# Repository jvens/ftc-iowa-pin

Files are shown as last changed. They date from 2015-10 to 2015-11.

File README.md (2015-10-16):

# FTC Iowa Pin

## Description
The FTC Iowa Pin is a small lapel pin in the shape of Iowa containing 24 low power LEDs making the FIRST logo.  The controler is a 8-bit PIC microcontroller made by Microchip.  The power comes from a single CR2032 battery giving the pin XX hours of continous use before the battery needs to be changed.  

## Hardware
The hardware can be split into three main sections: power, LED drivers, and MCU.  There are many ways that the circuit can be populated for various battery life to cost tradeoffs.  These will be better documented after the boards have been fully tested.  

### Power
The main power comes from a single CR2032 Lithium-Ion battery providing 225mA-hr of energy.  The battery supplies a voltage of 2-3 volts nominally which directly powers the MCU circuity (ToDo: add ability to use an LDO if I need a 1.8 V regulated supply).  The battery also drives the step up circuity which is made up of a boost regulator and optional charge pump.  The circuit contains pads for two different boost options and one charge pump options, and jumpers to choose between options.  The output of the step up circuit is 6 volts which is used to power the LED drivers.

### LED Drivers
The LEDs are grouped into 12 sets.  Each set has two LEDs in series.  The sets are grouped into two columns of six rows.  The columns connect Anodes and rows connect Cathodes of the LEDs.  Driving each Anode is a PMOS transistor.  The transistor can be used as a binary switch or an current limiting switch.  When used as a binary switch the pullup resistor turns the switch off when the MCU puts the line to high-Z, and the switch turns on when the MCU drives the line low.  When used as a current limiting switch the MCU outputs an analog voltage using its internal DAC which is amplified by the op-amps to drive the gate.  Each LED is turned on by driving its column high and its row low, and turned off by setting the row to high-Z.

### MCU
The MCU is a PIC16 made by Microchip.  It uses GPIOs to drive the LED rows, and either GPIO or DAC to drive the LED columns.  It also contains a UART Rx line for reprogramming, ICSP for initial programming, and power on reset circuit.  User interaction is done by a capacitive touch pad connecting to the MCU comparator.  The other side of the comparator is driven by the internal DAC to measure the charge time of the touch pad and parallel capacitance.

## Software
ToDo

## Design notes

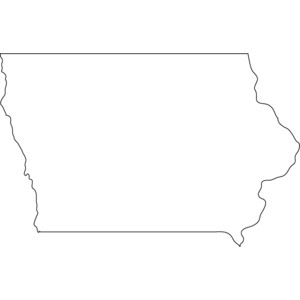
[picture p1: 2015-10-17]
schematic/iowa.jpg

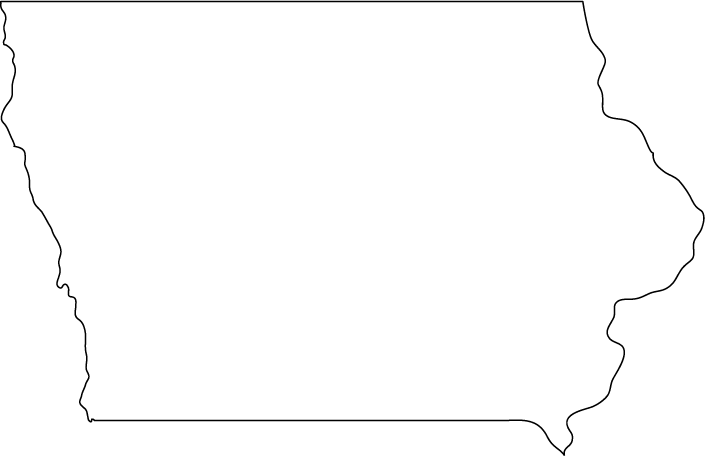
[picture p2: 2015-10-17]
schematic/ia.gif

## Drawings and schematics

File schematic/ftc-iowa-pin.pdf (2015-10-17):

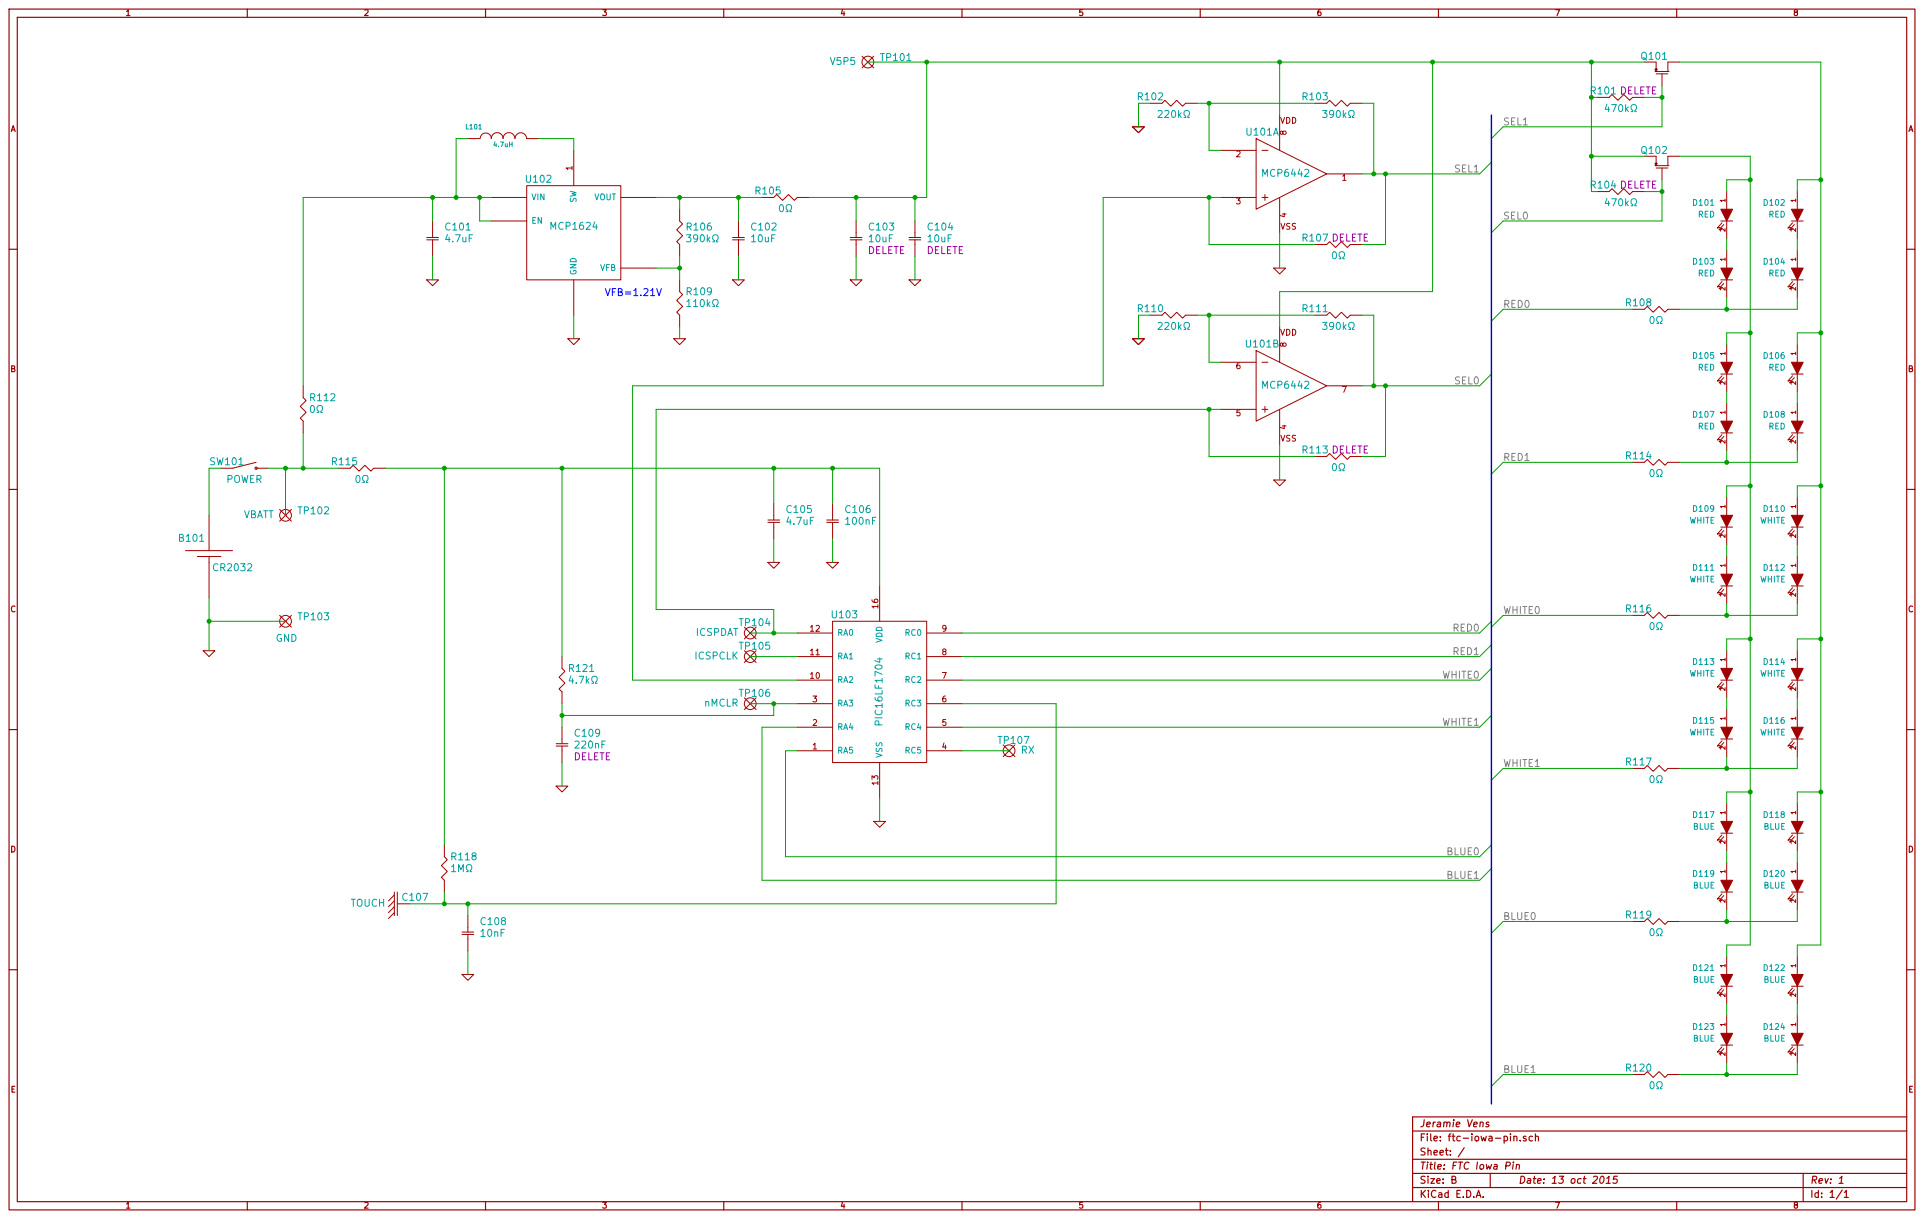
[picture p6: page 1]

Sheet: / Jeramie Vens
File: ftc-iowa-pin.sch

Title: FTC Iowa Pin

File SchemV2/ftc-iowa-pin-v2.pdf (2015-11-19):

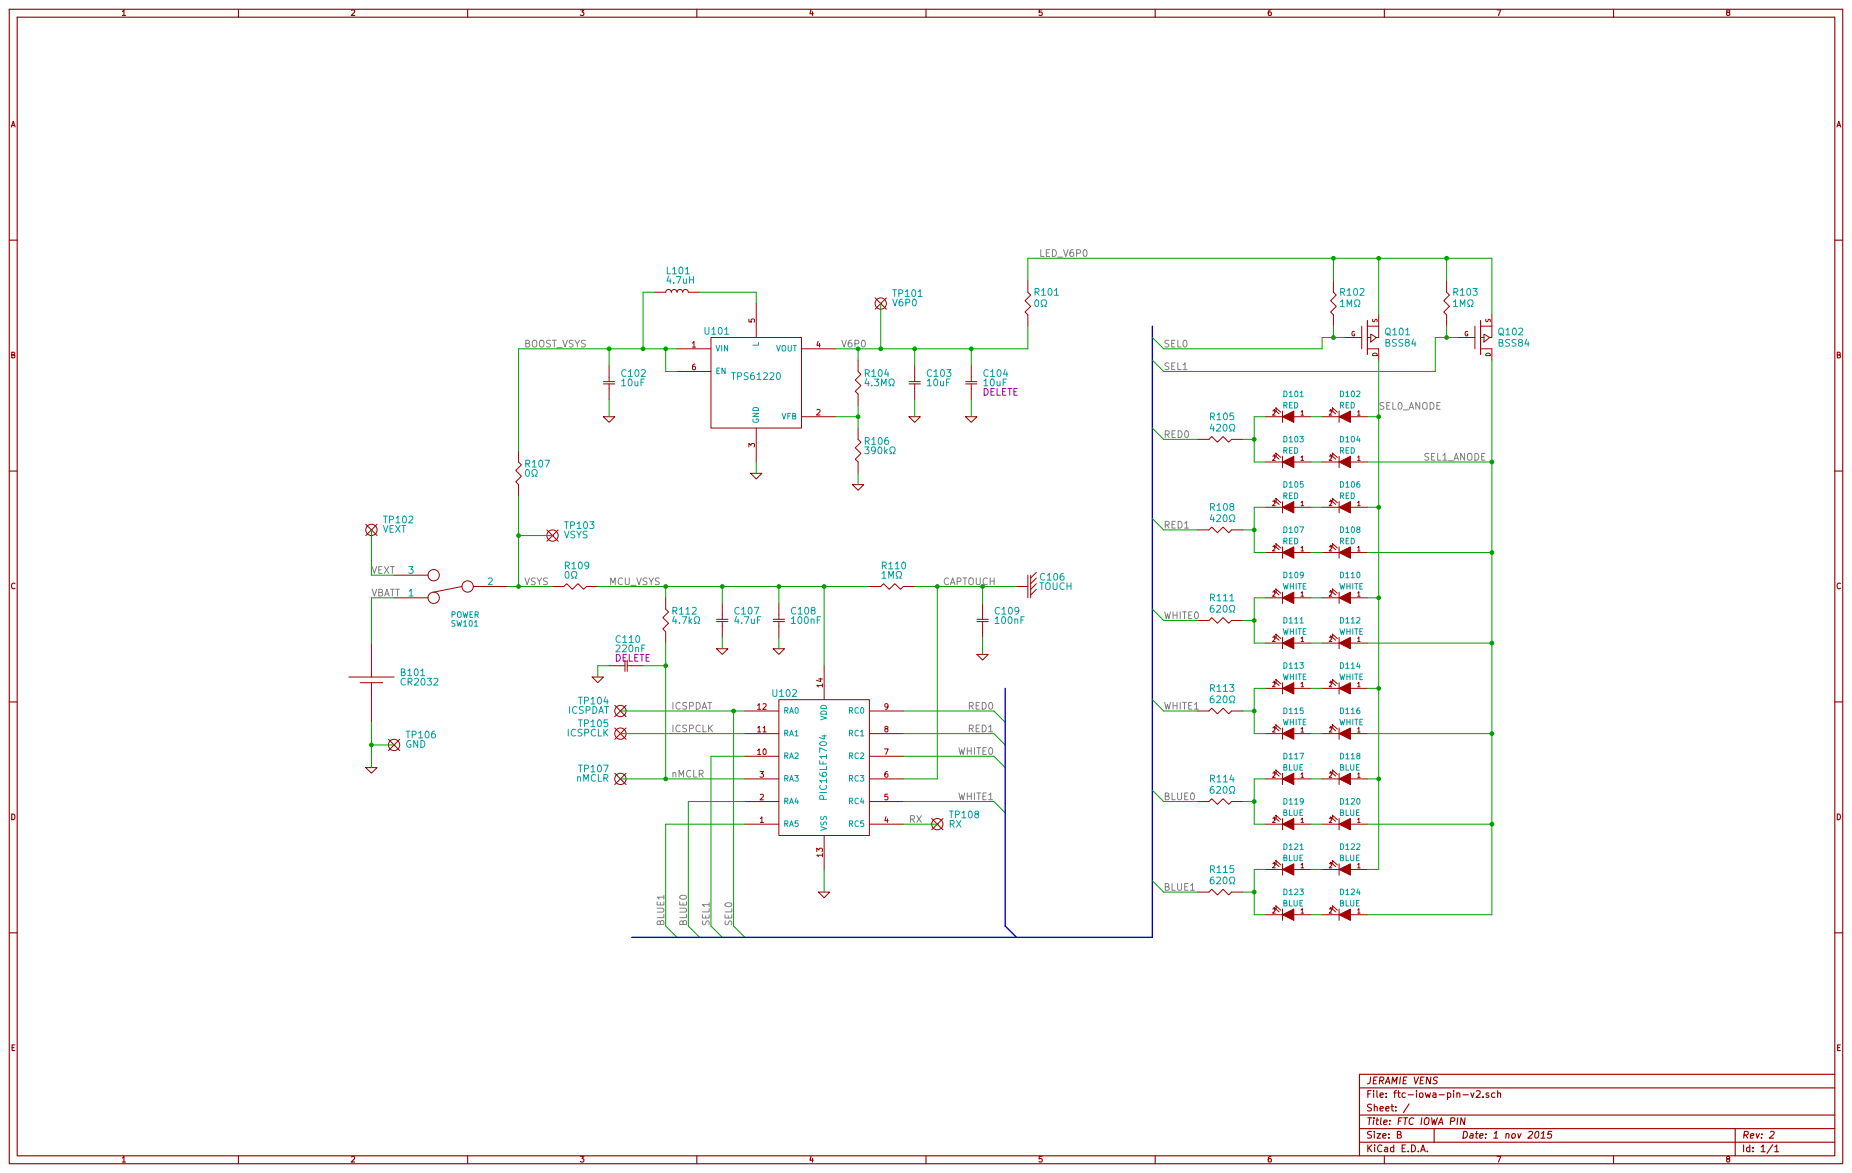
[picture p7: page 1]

JERAMIE VENS
File: ftc-iowa-pin-v2.sch
Sheet: /
Title: FTC IOWA PIN

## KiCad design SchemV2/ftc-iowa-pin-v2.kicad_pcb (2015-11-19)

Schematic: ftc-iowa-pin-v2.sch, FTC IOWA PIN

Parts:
B101: CR2032
C102, C103, C104: 10uF
C106: TOUCH
C107: 4.7uF
C108, C109: 100nF
C110: 220nF
D101, D102, D103, D104, D105, D106, D107, D108: RED
D109, D110, D111, D112, D113, D114, D115, D116: WHITE
D117, D118, D119, D120, D121, D122, D123, D124: BLUE
L101: 4.7uH
Q101, Q102: BSS84
R101, R107, R109: 0Ω
R102, R103, R110: 1MΩ
R104: 4.3MΩ
R105, R108: 420Ω
R106: 390kΩ
R111, R113, R114, R115: 620Ω
R112: 4.7kΩ
SW101: POWER
TP101: V6P0
TP102: VEXT
TP103: VSYS
TP104: ICSPDAT
TP105: ICSPCLK
TP106: GND
TP107: nMCLR
TP108: RX
U101: TPS61220
U102: PIC16LF1704

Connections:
/BLUE0: R114.2, U102.2 (RA4)
/BLUE1: R115.2, U102.1 (RA5)
/BOOST_VSYS: C102.1, L101.1, R107.2, U101.1 (VIN), U101.6 (EN)
/CAPTOUCH: C106.1, C109.1, R110.1, U102.6 (RC3)
/ICSPCLK: TP105.1, U102.11 (RA1)
/ICSPDAT: Q101.G, R102.1, TP104.1, U102.12 (RA0)
/LED_V6P0: Q101.S, Q102.S, R101.2, R102.2, R103.2
/MCU_VSYS: C107.1, C108.1, R109.1, R110.2, R112.2, U102.14 (VDD)
/RED0: R105.2, U102.9 (RC0)
/RED1: R108.2, U102.8 (RC1)
/RX: TP108.1, U102.4 (RC5)
/SEL0_ANODE: D102.1 (A), D106.1 (A), D110.1 (A), D114.1 (A), D118.1 (A), D122.1 (A), Q101.D
/SEL1: Q102.G, R103.1, U102.10 (RA2)
/SEL1_ANODE: D104.1 (A), D108.1 (A), D112.1 (A), D116.1 (A), D120.1 (A), D124.1 (A), Q102.D
/V6P0: C103.1, C104.1, R101.1, R104.2, TP101.1, U101.4 (VOUT)
/VBATT: B101.1, SW101.1
/VEXT: SW101.3, TP102.1
/VSYS: R107.1, R109.2, SW101.2, TP103.1
/WHITE0: R111.2, U102.7 (RC2)
/WHITE1: R113.2, U102.5 (RC4)
/nMCLR: C110.2, R112.1, TP107.1, U102.3 (RA3)
GND: B101.2, C102.2, C103.2, C104.2, C107.2, C108.2, C109.2, C110.1, R106.1, TP106.1, U101.3 (GND), U102.13 (VSS)
unnamed: L101.2, U101.5 (L)
unnamed: D121.2 (K), D123.2 (K), R115.1
unnamed: D121.1 (A), D122.2 (K)
unnamed: D117.2 (K), D119.2 (K), R114.1
unnamed: D119.1 (A), D120.2 (K)
unnamed: D123.1 (A), D124.2 (K)
unnamed: D115.1 (A), D116.2 (K)
unnamed: D113.2 (K), D115.2 (K), R113.1
unnamed: D113.1 (A), D114.2 (K)
unnamed: D109.2 (K), D111.2 (K), R111.1
unnamed: D111.1 (A), D112.2 (K)
unnamed: D105.2 (K), D107.2 (K), R108.1
unnamed: D107.1 (A), D108.2 (K)
unnamed: D105.1 (A), D106.2 (K)
unnamed: D101.2 (K), D103.2 (K), R105.1
unnamed: D103.1 (A), D104.2 (K)
unnamed: D117.1 (A), D118.2 (K)
unnamed: D109.1 (A), D110.2 (K)
unnamed: D101.1 (A), D102.2 (K)
unnamed: R104.1, R106.2, U101.2 (VFB)

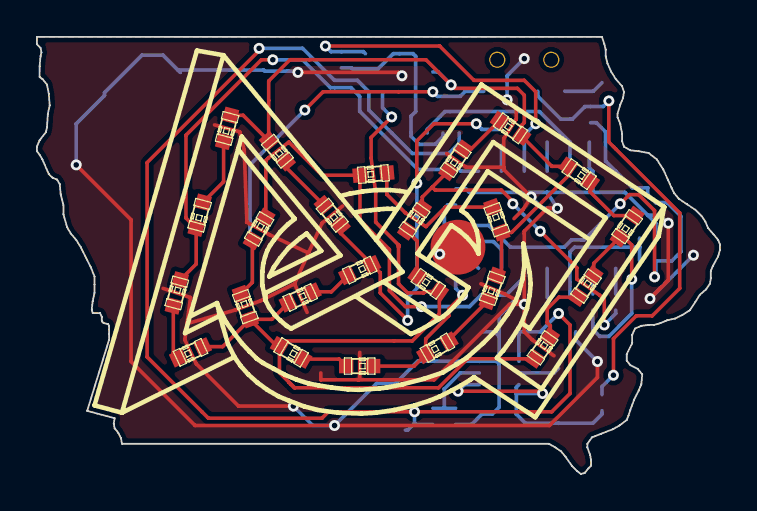
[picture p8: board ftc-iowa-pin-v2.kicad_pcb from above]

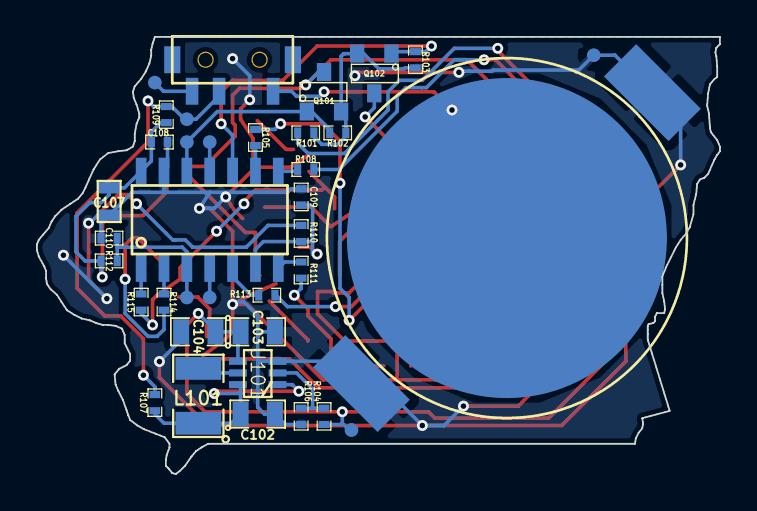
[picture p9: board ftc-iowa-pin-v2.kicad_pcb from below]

Board: 2 copper layers, 37.9 x 24.3 mm, 62 parts (37 on the bottom side), 42 nets.

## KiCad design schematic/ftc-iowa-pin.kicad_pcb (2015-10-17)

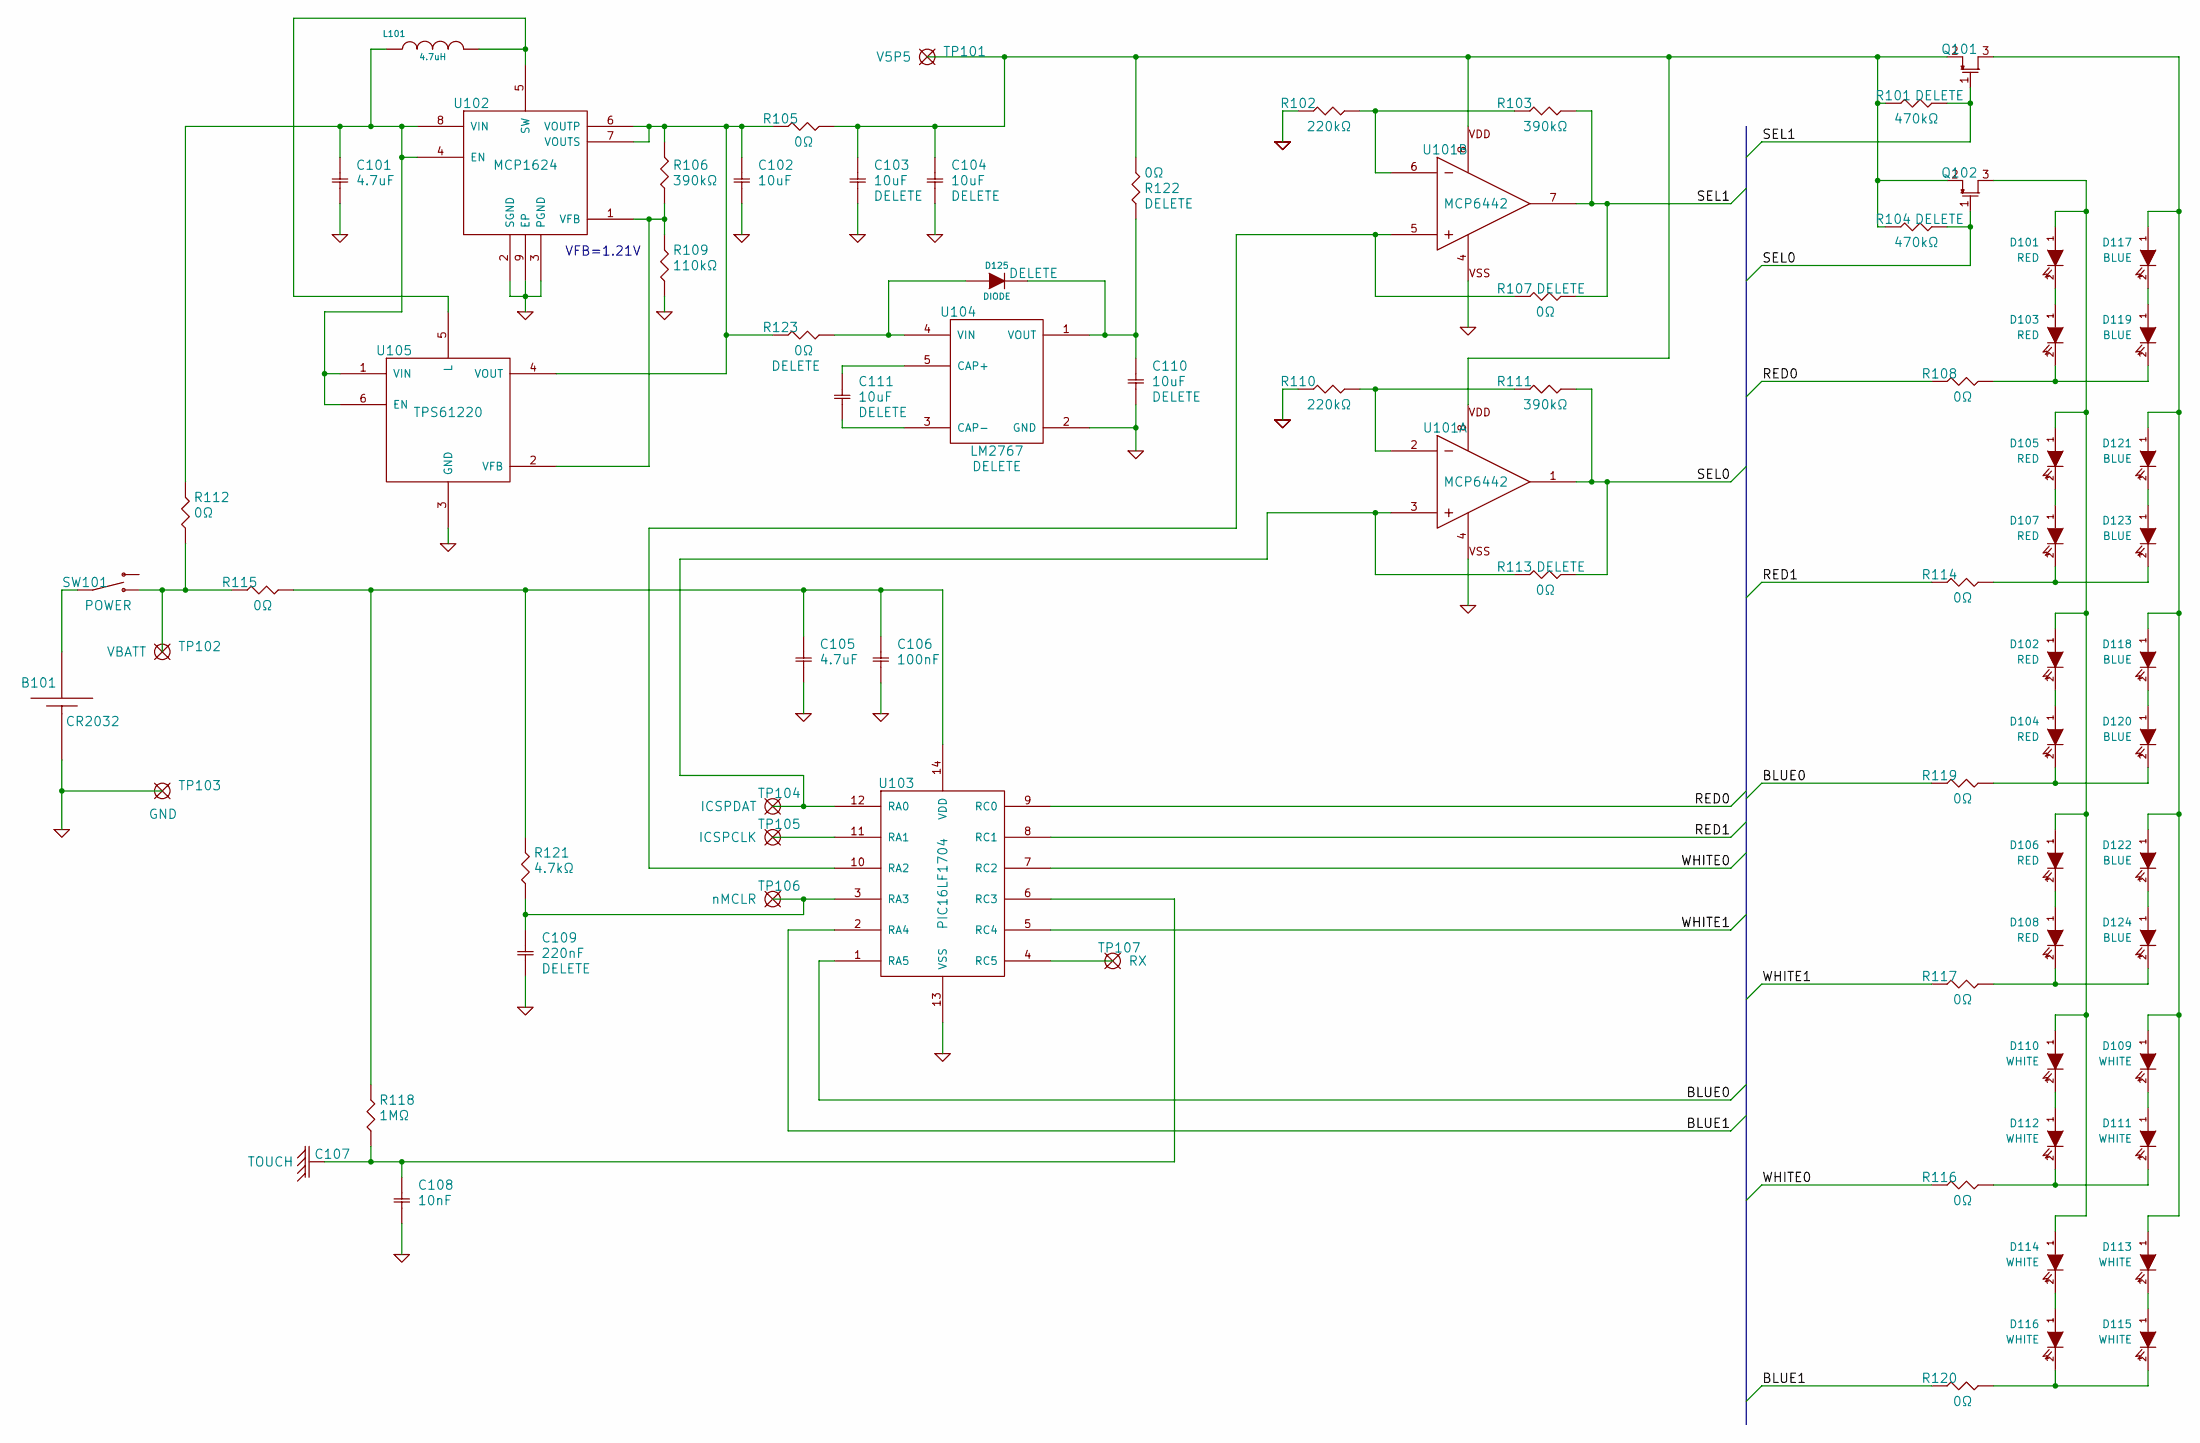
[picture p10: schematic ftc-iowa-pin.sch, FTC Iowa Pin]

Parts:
B101: CR2032
C101, C105: 4.7uF
C102, C103, C104, C110, C111: 10uF
C106: 100nF
C107: TOUCH
C108: 10nF
C109: 220nF
D101, D102, D103, D104, D105, D106, D107, D108: RED
D109, D110, D111, D112, D113, D114, D115, D116: WHITE
D117, D118, D119, D120, D121, D122, D123, D124: BLUE
D125: DIODE
L101: 4.7uH
Q101, Q102: PMOS
R101, R104: 470kΩ
R102, R110: 220kΩ
R103, R106, R111: 390kΩ
R105, R107, R108, R112, R113, R114, R115, R116, R117, R119, R120, R122, R123: 0Ω
R109: 110kΩ
R118: 1MΩ
R121: 4.7kΩ
SW101: POWER
TP101: V5P5
TP102: VBATT
TP103: GND
TP104: ICSPDAT
TP105: ICSPCLK
TP106: nMCLR
TP107: RX
U101: MCP6442
U102: MCP1624
U103: PIC16LF1704
U104: LM2767
U105: TPS61220

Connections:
/BLUE0: R119.1, U103.1 (RA5)
/BLUE1: R120.1, U103.2 (RA4)
/RED0: R108.1, U103.9 (RC0)
/RED1: R114.1, U103.8 (RC1)
/SEL0: Q102.1 (Gate), R104.2, R111.2, R113.2, U101.1 (OUT)
/SEL1: Q101.1 (Gate), R101.2, R103.2, R107.2, U101.7 (OUT)
/WHITE0: R116.1, U103.7 (RC2)
/WHITE1: R117.1, U103.5 (RC4)
GND: B101.2 (-), C101.2, C102.2, C103.2, C104.2, C105.2, C106.2, C108.2, C109.2, C110.2, R102.1, R109.1, R110.1, TP103.1, U101.4 (VSS), U102.2 (SGND), U102.3 (PGND), U102.9 (EP), U103.13 (VSS), U104.2 (GND), U105.3 (GND)
unnamed: C101.1, L101.1, R112.2, U102.4 (EN), U102.8 (VIN), U105.1 (VIN), U105.6 (EN)
unnamed: L101.2, U102.5 (SW), U105.5 (L)
unnamed: R113.1, TP104.1, U101.3 (+), U103.12 (RA0)
unnamed: R112.1, R115.1, SW101.1, TP102.1
unnamed: B101.1 (+), SW101.2
unnamed: R110.2, R111.1, U101.2 (-)
unnamed: R107.1, U101.5 (+), U103.10 (RA2)
unnamed: C107.1, C108.1, R118.1, U103.6 (RC3)
unnamed: R102.2, R103.1, U101.6 (-)
unnamed: TP107.1, U103.4 (RC5)
unnamed: TP105.1, U103.11 (RA1)
unnamed: R106.1, R109.2, U102.1 (VFB), U105.2 (VFB)
unnamed: C111.1, U104.5 (CAP+)
unnamed: C111.2, U104.3 (CAP-)
unnamed: D125.1 (A), R123.2, U104.4 (VIN)
unnamed: C110.1, D125.2 (K), R122.1, U104.1 (VOUT)
unnamed: D113.2 (K), D115.1 (A)
unnamed: C109.1, R121.1, TP106.1, U103.3 (RA3)
unnamed: C103.1, C104.1, Q101.2 (SOURCE), Q102.2 (SOURCE), R101.1, R104.1, R105.2, R122.2, TP101.1, U101.8 (VDD)
unnamed: D114.2 (K), D116.1 (A)
unnamed: C105.1, C106.1, R115.2, R118.2, R121.2, U103.14 (VDD)
unnamed: C102.1, R105.1, R106.2, R123.1, U102.6 (VOUTP), U102.7 (VOUTS), U105.4 (VOUT)
unnamed: D106.2 (K), D108.1 (A)
unnamed: D109.2 (K), D111.1 (A)
unnamed: D117.2 (K), D119.1 (A)
unnamed: D104.2 (K), D120.2 (K), R119.2
unnamed: D101.2 (K), D103.1 (A)
unnamed: D105.2 (K), D107.1 (A)
unnamed: D102.2 (K), D104.1 (A)
unnamed: D108.2 (K), D124.2 (K), R117.2
unnamed: D111.2 (K), D112.2 (K), R116.2
unnamed: D115.2 (K), D116.2 (K), R120.2
unnamed: D121.2 (K), D123.1 (A)
unnamed: D107.2 (K), D123.2 (K), R114.2
unnamed: D103.2 (K), D119.2 (K), R108.2
unnamed: D122.2 (K), D124.1 (A)
unnamed: D109.1 (A), D113.1 (A), D117.1 (A), D118.1 (A), D121.1 (A), D122.1 (A), Q101.3 (DRAIN)
unnamed: D101.1 (A), D102.1 (A), D105.1 (A), D106.1 (A), D110.1 (A), D114.1 (A), Q102.3 (DRAIN)
unnamed: D110.2 (K), D112.1 (A)
unnamed: D118.2 (K), D120.1 (A)

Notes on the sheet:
VFB=1.21V

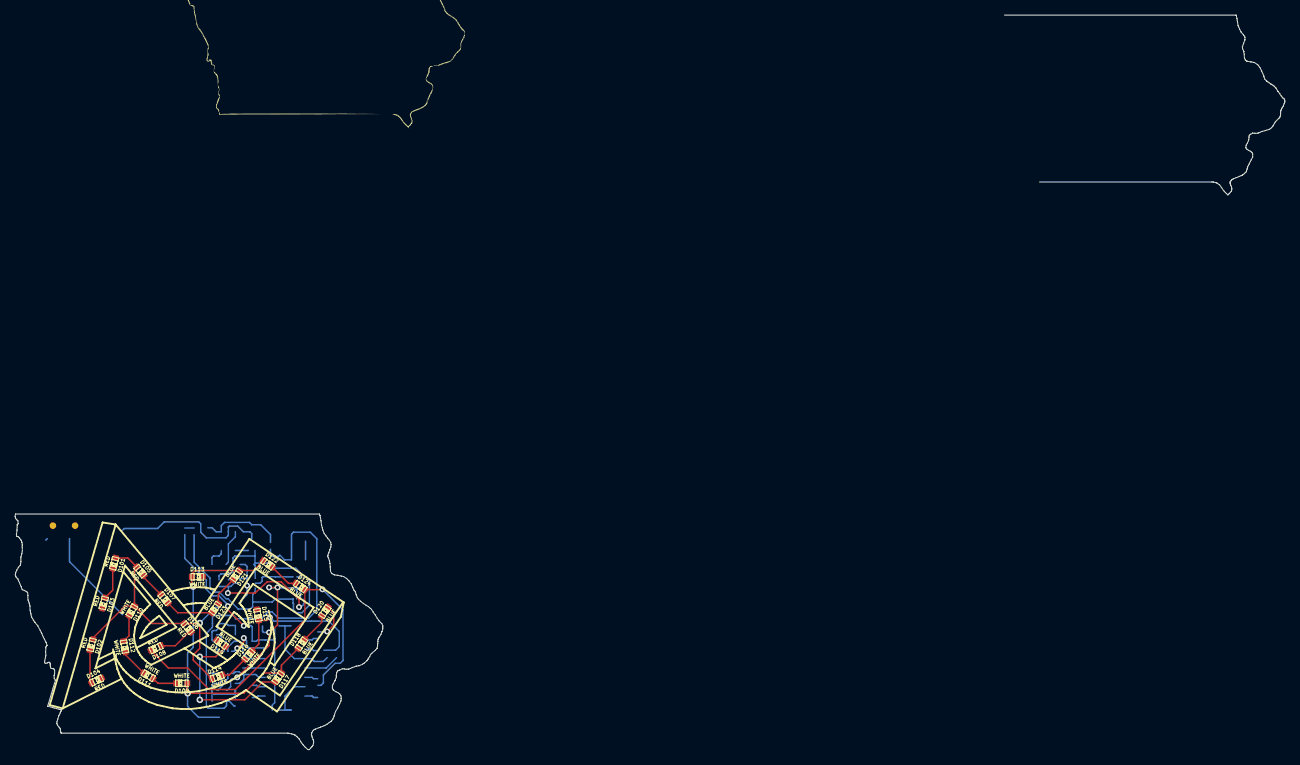
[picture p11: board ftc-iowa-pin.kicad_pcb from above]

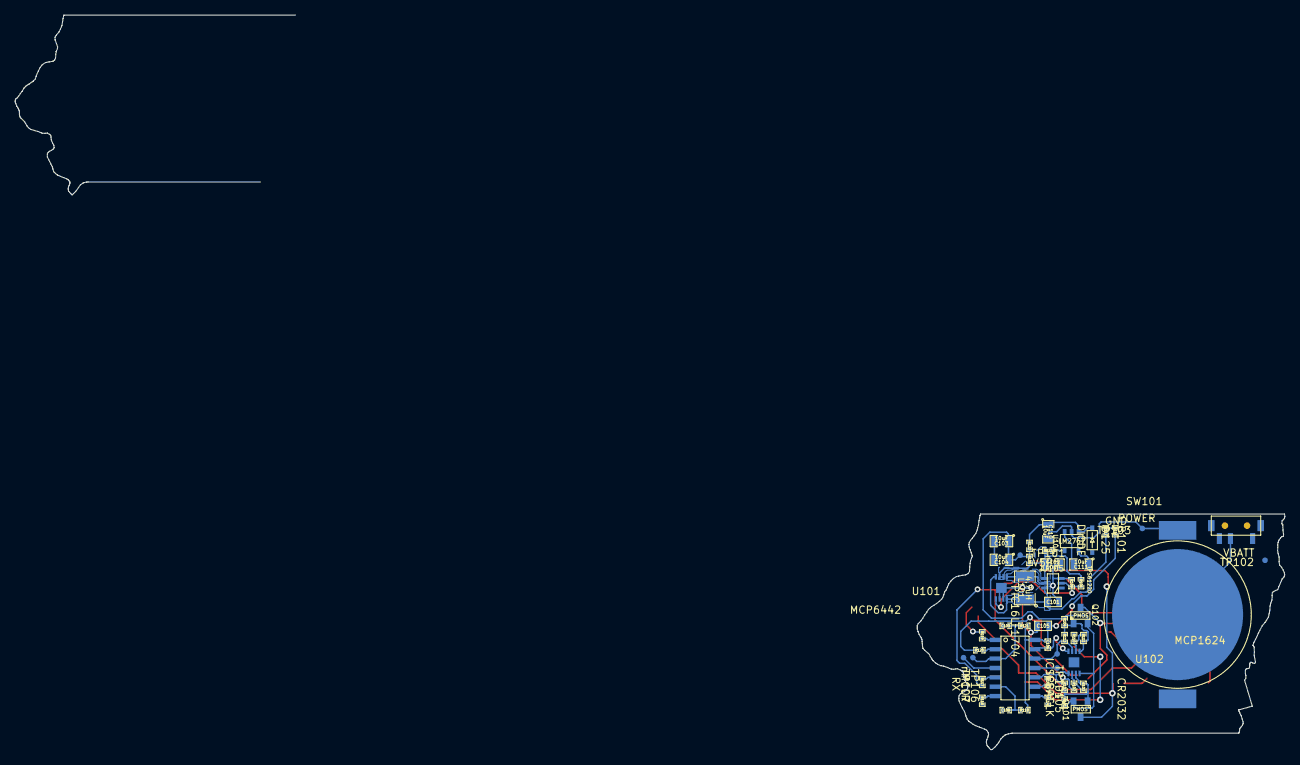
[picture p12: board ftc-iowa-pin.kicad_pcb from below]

Board: 2 copper layers, 49.9 x 32.0 mm, 79 parts (51 on the bottom side), 49 nets.

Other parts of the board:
VAL: REF; iowa_small
VAL#2: REF; iowa_50mm
VAL#3: REF; first_rotate_resize
VAL#4: REF; first_color

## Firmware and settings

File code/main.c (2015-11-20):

/*
 * File:   main.c
 * Author: vens
 *
 * Created on October 17, 2015, 7:44 PM
 */


#include <xc.h>

#define OUT
#define IN

typedef enum bool
{
    false=0, true
}bool;


const unsigned short a1[] = 
{
    12,
    0x5001,
    0x5002,
    0x5004,
    0x5008,
    0x5010,
    0x5020,
    0x5040,
    0x5080,
    0x5100,
    0x5200,
    0x5400,
    0x5800
};

unsigned short const * animation_table[] = {&a1};
unsigned short number_of_animations = 1;

/////////////////////////////////////////////////
//                                             //
//  FEATURE SELECTION                          //
//                                             //
/////////////////////////////////////////////////

//#define ENABLE_UART
//#define ENABLE_TOUCH
//#define ENABLE_DAC

//#define ENABLE_CIRCULAR_BUFFER

//-- dependencies
#ifdef ENABLE_UART
#ifndef ENABLE_CIRCULAR_BUFFER
#define ENABLE_CIRCULAR_BUFFER
#endif
#endif

/////////////////////////////////////////////////
//                                             //
//   INTERRUPT HANDLER                         //
//                                             //
/////////////////////////////////////////////////





/////////////////////////////////////////////////
//                                             //
//   PROCESSOR CORE FEATURES                   //
//                                             //
/////////////////////////////////////////////////

/**
 * Initialize the processors core features.
 * @details configure the processor to use the internal oscillator at 500kHz and set the WDT
 *          time out to 1ms.
 */
inline static void proc_init(void)
{
    // init oscillator
    OSCCON = 0x3A; // PLL disabled, f=500kHz, Internal osc
    
    // init watch dog timer
    WDTCON = 0x00; // set WDT time out to 1ms
}

/**
 * Enable the watchdog timer.
 */
inline void wdt_enable(void)
{
    WDTCON |= 0x01;
}

/**
 * Disable the watchdog timer.
 */
inline void wdt_disable(void)
{
    WDTCON &= ~0x01;
}

/////////////////////////////////////////////////
//                                             //
//   CIRCULAR BUFFER                           //
//                                             //
/////////////////////////////////////////////////

#ifdef ENABLE_CIRCULAR_BUFFER
struct circular_buffer
{
    char *buffer;
    unsigned char read_index;
    unsigned char write_index;
    unsigned char count;
    unsigned char size;
};

void cb_init(struct circular_buffer * cb, char * buffer, unsigned char size)
{
    cb->buffer = buffer;
    cb->read_index = 0;
    cb->write_index = 0;
    cb->count = 0;
    cb->size = size;
    return;
}

unsigned char cb_push(struct circular_buffer * cb, char data)
{
    if(cb->count == cb->size)
        return -1;
    
    cb->buffer[cb->write_index++] = data;
    cb->write_index %= cb->size;
    cb->count++;
    return cb->count;
}

unsigned char cb_pop(struct circular_buffer * cb, OUT char * data)
{
    unsigned char count;
    //proc_interrupt_disable();
    if(cb->count == 0)
        return -1;
    
    *data = cb->buffer[cb->read_index++];
    cb->read_index %= cb->size;
    cb->count --;
    count = cb->count;
    //proc_interrupt_enable();
    return count;
}

#endif

/////////////////////////////////////////////////
//                                             //
//   UART                                      //
//                                             //
/////////////////////////////////////////////////
/*
/// @todo catch errors

#ifdef ENABLE_UART
#define UART_RX_BUFFER_SIZE 32

static struct UART_DATA
{
    char rx_data[UART_RX_BUFFER_SIZE];
    struct circular_buffer rx_buffer;
}uart;
#endif
*/
/**
 * Initialize the UART module
 *
inline void uart_init(void)
{
#ifdef ENABLE_UART
    cb_init(&uart.rx_buffer, uart.rx_data, UART_RX_BUFFER_SIZE);
    
    BAUD1CON = 0x00;
    
    RC1STA = 0x90; // enabled, async mode
#else
    return;
#endif
}
*/
/**
 * Callback called anytime a new byte is available to read from the UART.  
 * @details This function is called by the ISR anytime new data is available to
 *          read from the UART module.  It grabs the new data and saves it, but
 *          does not process it.  The data is stored in the circular buffer
 *          uart.rx_buffer.
 *
inline static void uart_rx(void)
{
#ifdef ENABLE_UART
    unsigned char error = RCSTA;
    // if not error
    cb_push(&uart.rx_buffer, RCREG);
#else
    return;
#endif
}

static void uart_loop(void)
{
#ifdef ENABLE_UART
    static char string[16];
    static unsigned char i = 0;
    unsigned char count;
    char data;
    for(count = cb_pop(&uart.rx_buffer, &data);count > 0; count = cb_pop(&uart.rx_buffer, &data))
    {
        string[i++] = data;
        if(data == '\n')
        {
            // handle data
            i = 0;
        }
        else if(i == 16)
        {
            // buffer overrun
            
            i = 0;
            break;
        }
    }
#else
    return;
#endif
}
*/
/////////////////////////////////////////////////
//                                             //
//   DAC                                       //
//                                             //
/////////////////////////////////////////////////
/*
enum dac_source
{
    
};

static void dac_init(void)
{
#warning dac_init not implemented
}

static void dac_set_source(enum dac_source source)
{
    
}

static void dac_turn_on(void)
{
    
}

static void dac_turn_off(void)
{
    
}

static void dac_set(unsigned char value)
{
    
}
*/
/////////////////////////////////////////////////
//                                             //
//   GPIOs                                     //
//                                             //
/////////////////////////////////////////////////

/**
 * @brief Represents the registers for a GPIO bank.
 * @todo make these pointers constant
 */
struct gpio_reg
{
    /// The input read value
    volatile unsigned char * port;
    /// The direction, 0=output, 1=input
    volatile unsigned char * tris;
    /// The output latch value
    volatile unsigned char * lat;
    /// The input level to be considered 1
    volatile unsigned char * inlvl;
    /// Open drain enabled when 1
    volatile unsigned char * odcon;
    /// Turn on slewrate control
    volatile unsigned char * slrcon;
    /// enable weak pullups
    volatile unsigned char * wpu;
};

/// GPIO bank A
const struct gpio_reg GPIOA = {&PORTA, &TRISA, &LATA, &INLVLA, &ODCONA, &SLRCONA, &WPUA};
/// GPIO bank B
const struct gpio_reg GPIOC = {&PORTC, &TRISC, &LATC, &INLVLC, &ODCONC, &SLRCONC, &WPUC};

/**
 * @brief A single GPIO pin
 */
struct gpio_pin
{
    /// The register bank the pin is connected to
    const struct gpio_reg const * reg;
    /// The pin on the bank that is this GPIO
    unsigned char pin;
};

/**
 * Named GPIOs for this probject
 */
typedef enum gpio
{
    SEL0, SEL1, RED0, RED1, WHITE0, WHITE1, BLUE0, BLUE1
}gpio;

/// The GPIOs for this project
const struct gpio_pin gpios[] = 
{
    {&GPIOA, 0}, // SEL0
    {&GPIOA, 1}, // SEL1
    {&GPIOC, 0}, // RED0
    {&GPIOC, 1}, // RED1
    {&GPIOC, 2}, // WHITE0
    {&GPIOC, 4}, // WHITE1
    {&GPIOA, 4}, // BLUE0
    {&GPIOA, 5}  // BLUE1
};

typedef enum gpio_mode
{
    INPUT, OUTPUT, HIGHZ
}gpio_mode;

typedef enum gpio_value
{
    LOW = 0, HIGH
}gpio_value;

/// @def Set the @param bit of the @param byte to @param value
#define SET_BIT(byte, bit, value) (value ? byte |= 1 << bit : byte &= ~(1 << bit))

inline void gpio_setMode(gpio g, gpio_mode mode)
{
    switch (mode)
    {
        case INPUT:
        case HIGHZ:
            SET_BIT(*gpios[g].reg->tris, gpios[g].pin, 1);
            break;
        case OUTPUT:
            SET_BIT(*gpios[g].reg->tris, gpios[g].pin, 0);
    }
}

inline void gpio_setValue(gpio g, gpio_value value)
{
    SET_BIT(*gpios[g].reg->lat, gpios[g].pin, value);
}


inline void gpio_setPullup(gpio g, bool value)
{
    SET_BIT(*gpios[g].reg->wpu, gpios[g].pin, value);
}

inline void gpio_setOpenDrain(gpio g, bool value)
{
    SET_BIT(*gpios[g].reg->odcon, gpios[g].pin, value);
}

inline void gpio_limitSlewRate(gpio g, bool value)
{
    SET_BIT(*gpios[g].reg->slrcon, gpios[g].pin, value);
}

inline char gpio_readValue(gpio g)
{
    return (*gpios[g].reg->port & (1 << gpios[g].pin));
}

/////////////////////////////////////////////////
//                                             //
//   ANIMATION                                 //
//                                             //
/////////////////////////////////////////////////

struct animation
{
    unsigned short frames[128];         ///< Array of frame data
    unsigned char frame_number;         ///< number of current frame
    unsigned char number_of_frames;     ///< total number of frames in the array
}animation;

unsigned short animation_getNextFrame()
{
    animation.frame_number += 1;
    animation.frame_number %= animation.number_of_frames;
    return animation.frames[animation.frame_number];
}

void animation_load(unsigned short number)
{
    unsigned short const * a = animation_table[number];
    unsigned short i;
    animation.number_of_frames = a[0];
    for(i=0; i < animation.number_of_frames; i++)
    {
        animation.frames[i] = a[i+1];
    }
    animation.frame_number = 0;
}

/////////////////////////////////////////////////
//                                             //
//   LEDs                                      //
//                                             //
/////////////////////////////////////////////////

struct display
{
    unsigned red    : 4;
    unsigned white  : 4;
    unsigned blue   : 4;
};

enum led_state
{
    LED_STATE_RED0,
    LED_STATE_RED1,
    LED_STATE_WHITE0,
    LED_STATE_WHITE1,
    LED_STATE_BLUE0,
    LED_STATE_BLUE1
};

struct led_state_machine
{
    struct display current_display;
    unsigned char frame_length;         ///< The number of times this frame should be shown (0=allways show)
    unsigned char frame_time;           ///< The number of times this frame has been shown
    enum led_state state;               ///< State of the finite state machine
    unsigned short current_frame;
    
}led_state_machine;



void led_init()
{
    gpio_setMode(SEL0, HIGHZ);
    gpio_setMode(SEL1, HIGHZ);
    gpio_setMode(RED0, HIGHZ);
    gpio_setMode(RED1, HIGHZ);
    gpio_setMode(WHITE0, HIGHZ);
    gpio_setMode(WHITE1, HIGHZ);
    gpio_setMode(BLUE0, HIGHZ);
    gpio_setMode(BLUE1, HIGHZ);
    
    gpio_setPullup(SEL0, false);
    gpio_setPullup(SEL1, false);
    gpio_setPullup(RED0, false);
    gpio_setPullup(RED1, false);
    gpio_setPullup(WHITE0, false);
    gpio_setPullup(WHITE1, false);
    gpio_setPullup(BLUE0, false);
    gpio_setPullup(BLUE1, false);
    
    gpio_setOpenDrain(SEL0, true);
    gpio_setOpenDrain(SEL1, true);
    gpio_setOpenDrain(RED0, true);
    gpio_setOpenDrain(RED1, true);
    gpio_setOpenDrain(WHITE0, true);
    gpio_setOpenDrain(WHITE1, true);
    gpio_setOpenDrain(BLUE0, true);
    gpio_setOpenDrain(BLUE1, true);
    
    gpio_setValue(SEL0, LOW);
    gpio_setValue(SEL1, LOW);
    gpio_setValue(RED0, LOW);
    gpio_setValue(RED1, LOW);
    gpio_setValue(WHITE0, LOW);
    gpio_setValue(WHITE1, LOW);
    gpio_setValue(BLUE0, LOW);
    gpio_setValue(BLUE1, LOW);
}

void led_turnOff(gpio g)
{
    gpio_setMode(g, HIGHZ);
    gpio_setMode(SEL0, HIGHZ);
    gpio_setMode(SEL1, HIGHZ);
}

void led_turnOn(gpio g, unsigned char sel0, unsigned char sel1)
{
    gpio_setMode(SEL0, sel0 ? OUTPUT : HIGHZ);
    gpio_setMode(SEL1, sel1 ? OUTPUT : HIGHZ);
    gpio_setMode(g, OUTPUT);
}

void led_loadNextFrame(void)
{
    unsigned short frame = animation_getNextFrame();
    led_state_machine.current_display.red = frame & 0x000F;
    led_state_machine.current_display.white=(frame & 0x00F0) >> 4;
    led_state_machine.current_display.blue = (frame & 0x0F00) >> 8;
    led_state_machine.frame_length = (frame & 0xF000) >> 8;          // note that this is multiplied by 16 => 1 length ~= 100ms
    led_state_machine.frame_time = 0;
}

void led_loop()
{
    switch(led_state_machine.state)
    {
        case LED_STATE_RED0:
            led_turnOff(BLUE1);
            led_turnOn(RED0, led_state_machine.current_display.red & 0x1, led_state_machine.current_display.red & 0x2);
            led_state_machine.state = LED_STATE_RED1;
            break;
        case LED_STATE_RED1:
            led_turnOff(RED0);
            led_turnOn(RED1, led_state_machine.current_display.red & 0x4, led_state_machine.current_display.red & 0x8);
            led_state_machine.state = LED_STATE_WHITE0;
            break;
        case LED_STATE_WHITE0:
            led_turnOff(RED1);
            led_turnOn(WHITE0, led_state_machine.current_display.white & 0x1, led_state_machine.current_display.white & 0x2);
            led_state_machine.state = LED_STATE_WHITE1;
            break;
        case LED_STATE_WHITE1:
            led_turnOff(WHITE0);
            led_turnOn(WHITE1, led_state_machine.current_display.white & 0x4, led_state_machine.current_display.white & 0x8);
            led_state_machine.state = LED_STATE_BLUE0;
            break;
        case LED_STATE_BLUE0:
            led_turnOff(WHITE1);
            led_turnOn(BLUE0, led_state_machine.current_display.blue & 0x1, led_state_machine.current_display.blue & 0x2);
            led_state_machine.state = LED_STATE_BLUE1;
            break;
        case LED_STATE_BLUE1:
            led_turnOff(BLUE0);
            led_turnOn(BLUE1, led_state_machine.current_display.blue & 0x4, led_state_machine.current_display.blue & 0x8);
            led_state_machine.state = LED_STATE_RED0;
            led_state_machine.frame_time ++;
            if(led_state_machine.frame_length && led_state_machine.frame_time == led_state_machine.frame_length)
            {
                led_loadNextFrame();
            }
            break;
    }
}



/////////////////////////////////////////////////
//                                             //
//   MAIN                                      //
//                                             //
/////////////////////////////////////////////////

void main(void) {
    proc_init();
    // dac_init();
    led_init();
    // uart_init();
    // touch_init();
    
    animation_load(0);
    
    wdt_enable();
    while(1)    // this loop is approxamently every 1ms
    {
        // set led values
        led_loop();
        //uart_loop();
    //     proc_sleep();
    }
    
    
    return;
}

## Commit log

2015-11-01 Pushing second version of the schematic for OSH park
    [ftc-iowa-pin-v2.kicad_pcb, ftc-iowa-pin-v2.sch]
2015-11-02 Added copper pour
    [ftc-iowa-pin-v2.kicad_pcb]
2015-11-02 cleaned up silk
    [ftc-iowa-pin-v2.kicad_pcb]
